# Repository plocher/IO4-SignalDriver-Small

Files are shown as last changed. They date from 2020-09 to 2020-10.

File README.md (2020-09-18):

# IO4-SignalDriver-Small
## License: CERN Open Hardware Licence v1.2

IO4 Output adapter driver for a 2-head signal mast

Takes an IO4-Output and drives 2x 3-LED common Anode signal heads using a demultiplexor logic chip.

Designed in conjunction with Jay Beckham for his South Shore Lines layout

Circuit info:
  * The board is driven from an IO4 port that carries +5, GND and 4x output signals.
  * Signal heads / LEDs are "common anode" - pin4 of the signal head connector is VCC, the "colors" pins are driven LOW to energize the LED.
  * The board can drive 2x signal heads, each with R, Y, G and DARK aspects
      * Control signals 1 & 2 and  3 & 4, each control one head:
          : 00 - Green
          : 01 - Yellow
          : 10 - Red
          : 11 - Dark
  * This board does not have provision for adjustable LED brightness.  The resistors are fixed at production time for high efficiency LEDS used in SPCoast's Simple Signal masts.

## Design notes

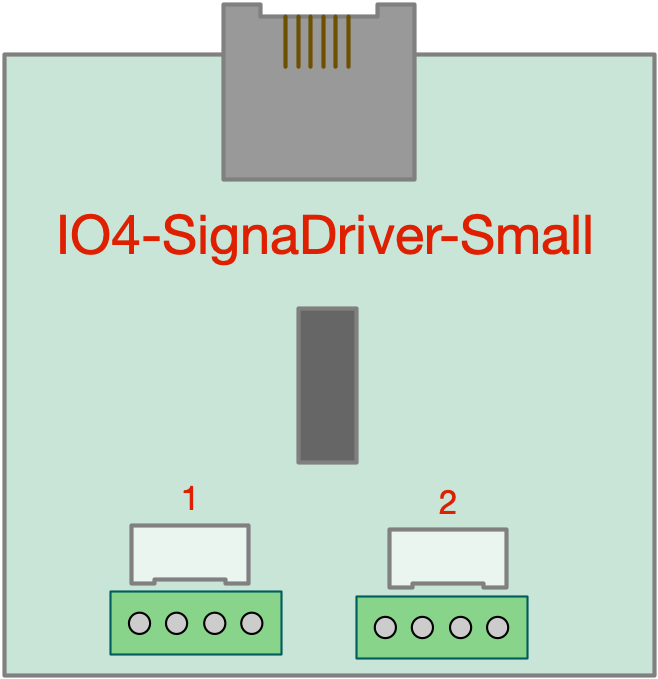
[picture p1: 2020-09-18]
IO4-SignalDriver-Small-Graphic.png

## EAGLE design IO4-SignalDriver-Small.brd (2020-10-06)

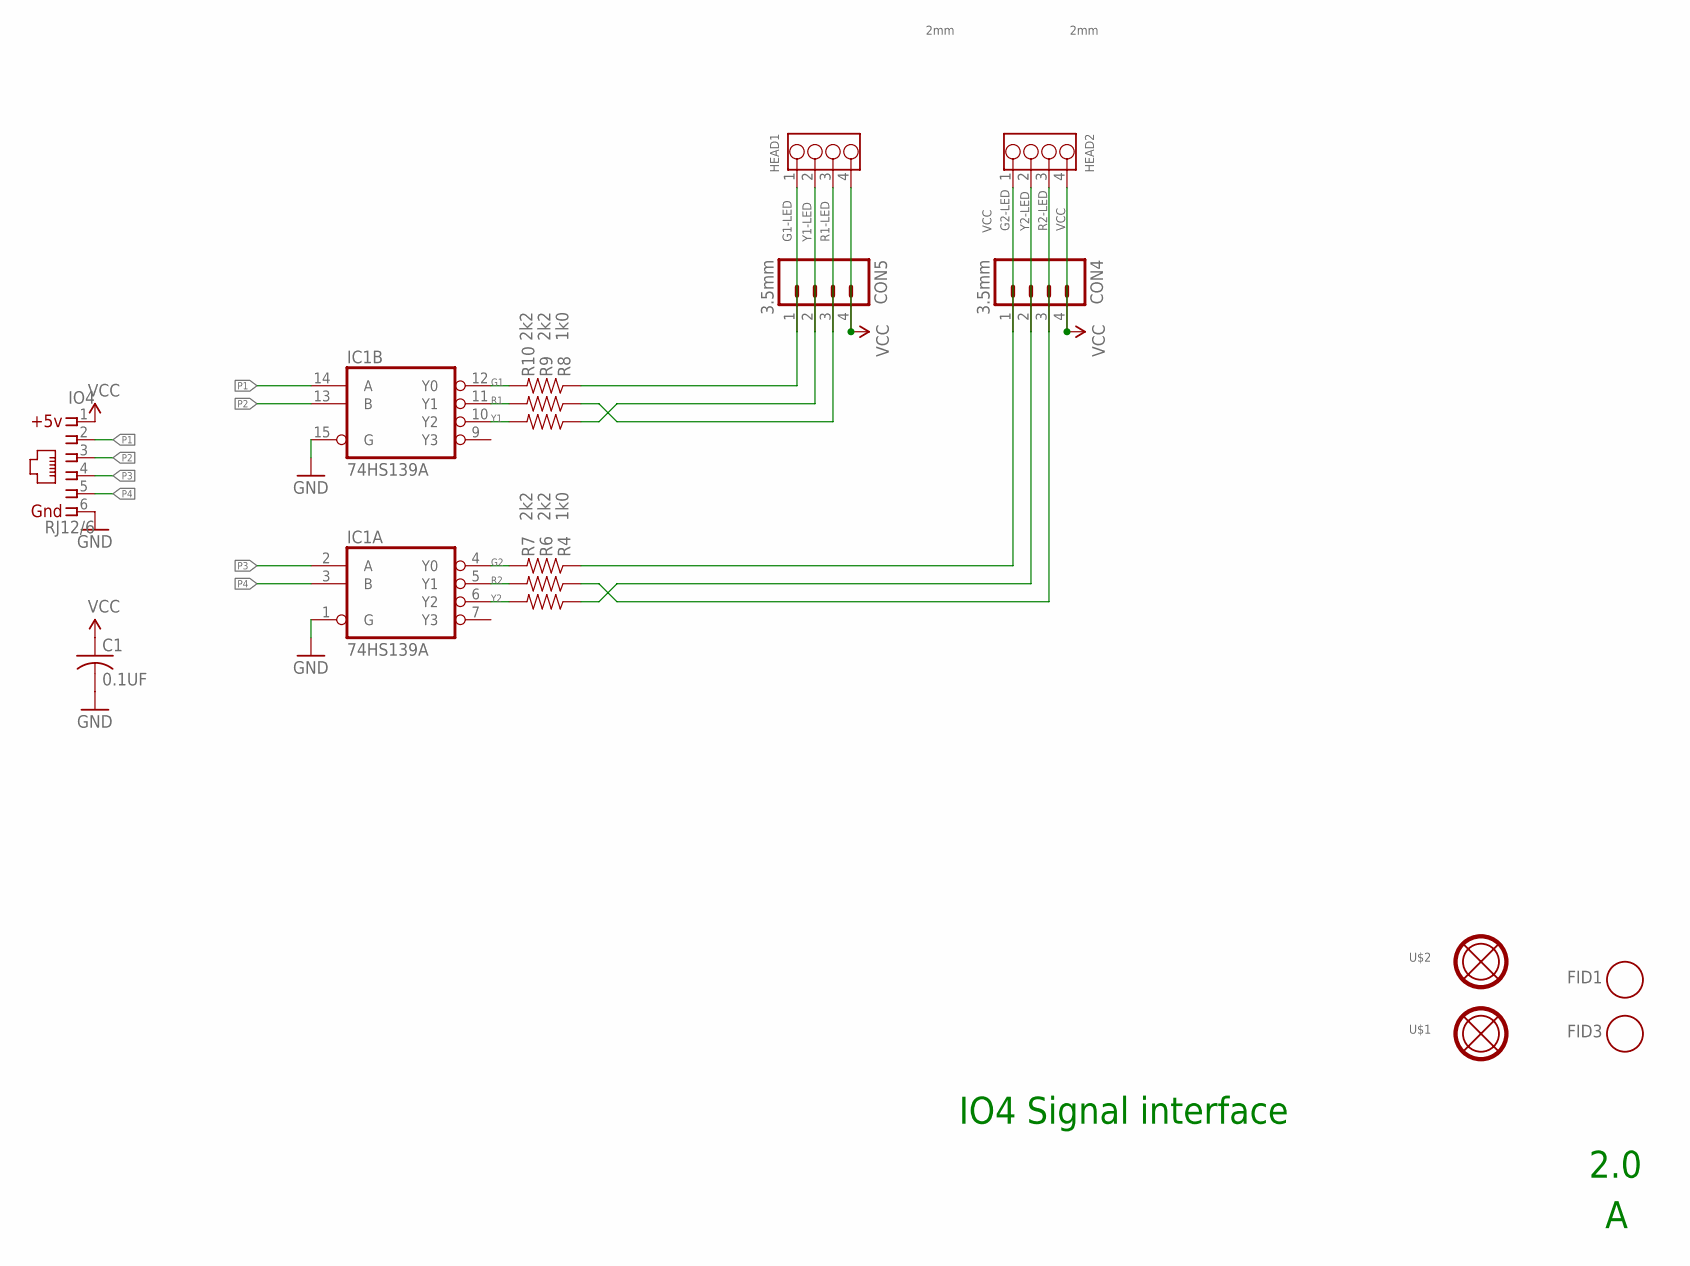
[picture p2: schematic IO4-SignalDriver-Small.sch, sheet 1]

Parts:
C1: 0.1UF; 0603-CAP
CON4, CON5: 3.5mm; SCREWTERMINAL-3.5MM-4
FID1, FID3: FIDUCIAL; FIDUCIAL_1MM
HEAD1, HEAD2: 2mm; 4P-2.0
IC1: 74HS139A; SO16
IO4: RJ12/6; RJ25-INVERTED
R4, R8: 1k0; 0603-RES
R6, R7, R9, R10: 2k2; 0603-RES
U$1, U$2: MOUNTINGHOLE

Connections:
G1: IC1.12 (Y0), R10.2
G1-LED: CON5.1, HEAD1.1, R10.1
G2: IC1.4 (Y0), R7.2
G2-LED: CON4.1, HEAD2.1, R7.1
GND: C1.2, IC1.1 (G), IC1.8 (GND), IC1.15 (G), IO4.6
P1: IC1.14 (A), IO4.2
P2: IC1.13 (B), IO4.3
P3: IC1.2 (A), IO4.4
P4: IC1.3 (B), IO4.5
R1: IC1.11 (Y1), R9.2
R1-LED: CON5.3, HEAD1.3, R9.1
R2: IC1.5 (Y1), R6.2
R2-LED: CON4.3, HEAD2.3, R6.1
VCC: C1.1, CON4.4, CON5.4, HEAD1.4, HEAD2.4, IC1.16 (VCC), IO4.1
Y1: IC1.10 (Y2), R8.2
Y1-LED: CON5.2, HEAD1.2, R8.1
Y2: IC1.6 (Y2), R4.2
Y2-LED: CON4.2, HEAD2.2, R4.1

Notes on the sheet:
IO4 Signal interface
2.0

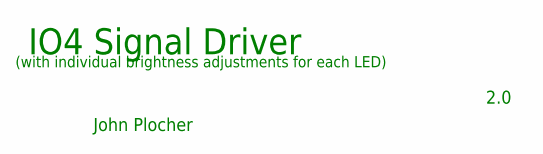
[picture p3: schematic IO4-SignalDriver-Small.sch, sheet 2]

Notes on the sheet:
(with individual brightness adjustments for each LED)
John Plocher
2.0
IO4 Signal Driver

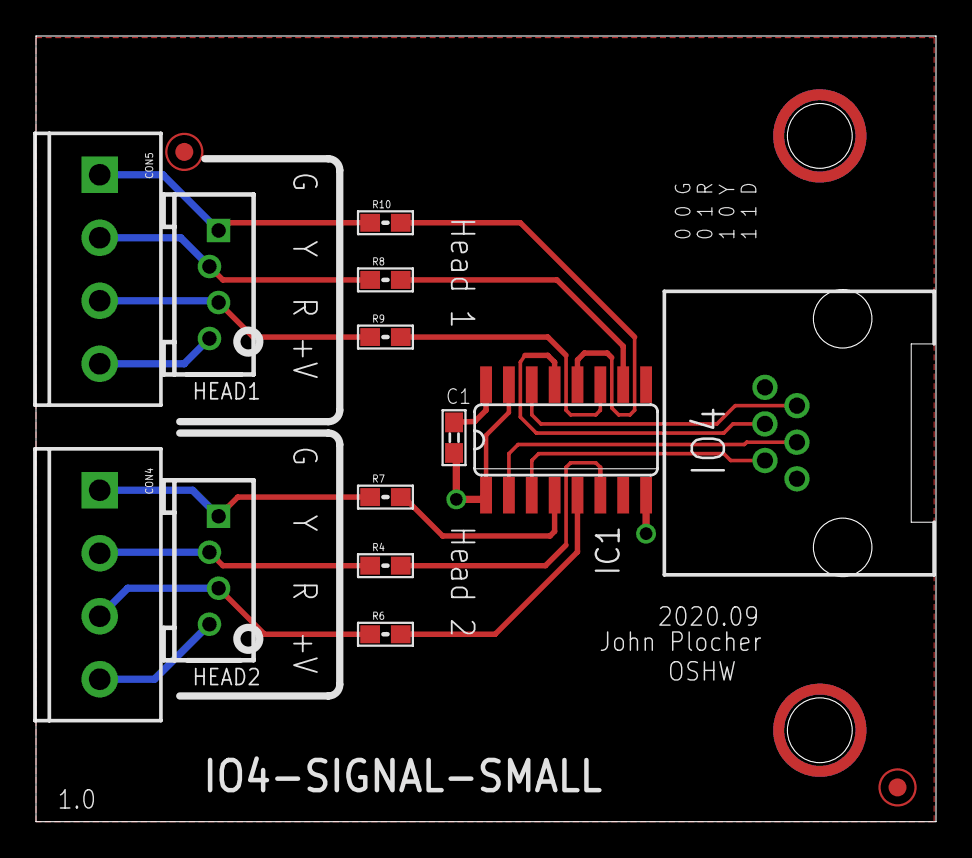
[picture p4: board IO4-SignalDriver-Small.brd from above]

Board: 2 copper layers, 50.0 x 43.6 mm, 17 parts (0 on the bottom side), 18 nets.

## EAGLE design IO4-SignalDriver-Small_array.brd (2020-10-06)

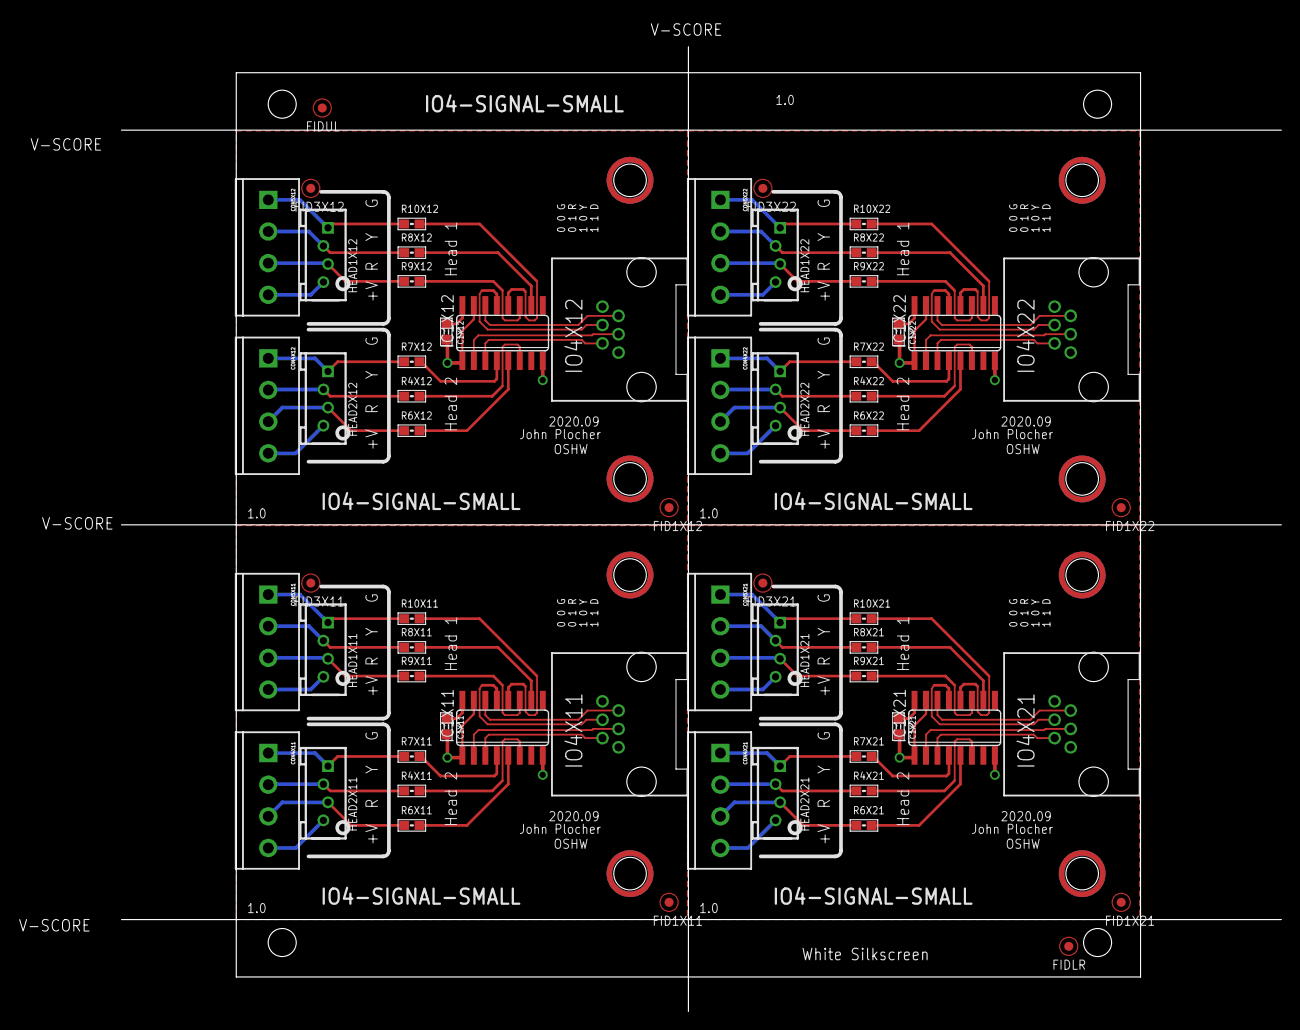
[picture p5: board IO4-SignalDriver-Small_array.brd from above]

Board: 2 copper layers, 100.0 x 100.0 mm, 71 parts (0 on the bottom side), 72 nets.

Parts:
BOARD: BOARD; BOARD-10X10-2X2-PANEL
C1X11, C1X12, C1X21, C1X22: 0.1UF; 0603-CAP
CON4X11, CON4X12, CON4X21, CON4X22, CON5X11, CON5X12, CON5X21, CON5X22: 3.5mm; SCREWTERMINAL-3.5MM-4
FID1X11, FID1X12, FID1X21, FID1X22, FID3X11, FID3X12, FID3X21, FID3X22: FIDUCIAL; FIDUCIAL_1MM
FIDLR: FIDUCIAL; FIDUCIAL_1MM
FIDUL: FIDUCIAL; FIDUCIAL_1MM
HEAD1X11, HEAD1X12, HEAD1X21, HEAD2X11, HEAD2X21: 2mm; 4P-2.0
HEAD1X22: Head 1; 4P-2.0
HEAD2X12, HEAD2X22: Head 2; 4P-2.0
IC1X11, IC1X12, IC1X21, IC1X22: 74HS139A; SO16
IO4X11, IO4X12, IO4X21, IO4X22: RJ12/6; RJ25-INVERTED
R4X11, R4X12, R4X21, R4X22, R8X11, R8X12, R8X21, R8X22: 1k0; 0603-RES
R6X11, R6X12, R6X21, R6X22, R7X11, R7X12, R7X21, R7X22, R9X11, R9X12, R9X21, R9X22, R10X11, R10X12, R10X21, R10X22: 2k2; 0603-RES
U$1X11, U$1X12, U$1X21, U$1X22, U$2X11, U$2X12, U$2X21, U$2X22: MOUNTINGHOLE

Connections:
G1-LEDX11: CON5X11.1, HEAD1X11.1, R10X11.1
G1-LEDX12: CON5X12.1, HEAD1X12.1, R10X12.1
G1-LEDX21: CON5X21.1, HEAD1X21.1, R10X21.1
G1-LEDX22: CON5X22.1, HEAD1X22.1, R10X22.1
G1X11: IC1X11.12, R10X11.2
G1X12: IC1X12.12, R10X12.2
G1X21: IC1X21.12, R10X21.2
G1X22: IC1X22.12, R10X22.2
G2-LEDX11: CON4X11.1, HEAD2X11.1, R7X11.1
G2-LEDX12: CON4X12.1, HEAD2X12.1, R7X12.1
G2-LEDX21: CON4X21.1, HEAD2X21.1, R7X21.1
G2-LEDX22: CON4X22.1, HEAD2X22.1, R7X22.1
G2X11: IC1X11.4, R7X11.2
G2X12: IC1X12.4, R7X12.2
G2X21: IC1X21.4, R7X21.2
G2X22: IC1X22.4, R7X22.2
GNDX11: C1X11.2, IC1X11.1, IC1X11.8, IC1X11.15, IO4X11.6
GNDX12: C1X12.2, IC1X12.1, IC1X12.8, IC1X12.15, IO4X12.6
GNDX21: C1X21.2, IC1X21.1, IC1X21.8, IC1X21.15, IO4X21.6
GNDX22: C1X22.2, IC1X22.1, IC1X22.8, IC1X22.15, IO4X22.6
P1X11: IC1X11.14, IO4X11.2
P1X12: IC1X12.14, IO4X12.2
P1X21: IC1X21.14, IO4X21.2
P1X22: IC1X22.14, IO4X22.2
P2X11: IC1X11.13, IO4X11.3
P2X12: IC1X12.13, IO4X12.3
P2X21: IC1X21.13, IO4X21.3
P2X22: IC1X22.13, IO4X22.3
P3X11: IC1X11.2, IO4X11.4
P3X12: IC1X12.2, IO4X12.4
P3X21: IC1X21.2, IO4X21.4
P3X22: IC1X22.2, IO4X22.4
P4X11: IC1X11.3, IO4X11.5
P4X12: IC1X12.3, IO4X12.5
P4X21: IC1X21.3, IO4X21.5
P4X22: IC1X22.3, IO4X22.5
R1-LEDX11: CON5X11.3, HEAD1X11.3, R9X11.1
R1-LEDX12: CON5X12.3, HEAD1X12.3, R9X12.1
R1-LEDX21: CON5X21.3, HEAD1X21.3, R9X21.1
R1-LEDX22: CON5X22.3, HEAD1X22.3, R9X22.1
R1X11: IC1X11.11, R9X11.2
R1X12: IC1X12.11, R9X12.2
R1X21: IC1X21.11, R9X21.2
R1X22: IC1X22.11, R9X22.2
R2-LEDX11: CON4X11.3, HEAD2X11.3, R6X11.1
R2-LEDX12: CON4X12.3, HEAD2X12.3, R6X12.1
R2-LEDX21: CON4X21.3, HEAD2X21.3, R6X21.1
R2-LEDX22: CON4X22.3, HEAD2X22.3, R6X22.1
R2X11: IC1X11.5, R6X11.2
R2X12: IC1X12.5, R6X12.2
R2X21: IC1X21.5, R6X21.2
R2X22: IC1X22.5, R6X22.2
VCCX11: C1X11.1, CON4X11.4, CON5X11.4, HEAD1X11.4, HEAD2X11.4, IC1X11.16, IO4X11.1
VCCX12: C1X12.1, CON4X12.4, CON5X12.4, HEAD1X12.4, HEAD2X12.4, IC1X12.16, IO4X12.1
VCCX21: C1X21.1, CON4X21.4, CON5X21.4, HEAD1X21.4, HEAD2X21.4, IC1X21.16, IO4X21.1
VCCX22: C1X22.1, CON4X22.4, CON5X22.4, HEAD1X22.4, HEAD2X22.4, IC1X22.16, IO4X22.1
Y1-LEDX11: CON5X11.2, HEAD1X11.2, R8X11.1
Y1-LEDX12: CON5X12.2, HEAD1X12.2, R8X12.1
Y1-LEDX21: CON5X21.2, HEAD1X21.2, R8X21.1
Y1-LEDX22: CON5X22.2, HEAD1X22.2, R8X22.1
Y1X11: IC1X11.10, R8X11.2
Y1X12: IC1X12.10, R8X12.2
Y1X21: IC1X21.10, R8X21.2
Y1X22: IC1X22.10, R8X22.2
Y2-LEDX11: CON4X11.2, HEAD2X11.2, R4X11.1
Y2-LEDX12: CON4X12.2, HEAD2X12.2, R4X12.1
Y2-LEDX21: CON4X21.2, HEAD2X21.2, R4X21.1
Y2-LEDX22: CON4X22.2, HEAD2X22.2, R4X22.1
Y2X11: IC1X11.6, R4X11.2
Y2X12: IC1X12.6, R4X12.2
Y2X21: IC1X21.6, R4X21.2
Y2X22: IC1X22.6, R4X22.2

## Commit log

2020-09-18 Initial version
    [IO4SignalDriver-Small.brd, IO4SignalDriver-Small.sch, IO4SignalDriver-Small_array.brd]
2020-10-05 added values for connectors
    [IO4-SignalDriver-Small.brd, IO4-SignalDriver-Small.sch, IO4-SignalDriver-Small_array.brd]
2020-10-06 normalized values
    [IO4-SignalDriver-Small.brd, IO4-SignalDriver-Small.sch, IO4-SignalDriver-Small_array.brd]
